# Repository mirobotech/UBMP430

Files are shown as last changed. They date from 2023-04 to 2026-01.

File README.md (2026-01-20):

# UBMP430
 
UBMP430 (USB-Based Beginner Multipurpose Project 4, rev. 3) KiCad schematic and PCB design files.

UBMP430 is a simple, versatile, and inexpensive microcontroller development system for everyone! The UBMP430 circuit board has a variety of simple I/O devices built-in so beginners can learn to code and make an assortment of different projects using just the parts on UBMP430 – no breadboarding, shields, or other modules are required, and external devices can be added using the expansion header. 

UBMP430 was designed for learning or teaching PIC programming in C or assembly language using either Microchip’s MPLAB X IDE or their MPLAB Xpress Cloud-based IDE. The [USB µC bootloader](https://hackaday.io/project/63204-usb-c-usb-pic-bootloader) allows UBMP430 to appear as a mass storage drive for easy programming. Simply drag and drop a compiled .hex file onto the ***PIC16F1459*** drive that shows up in your computer's device manager, and your program will start to run as soon as the file is transferred.

The bootloader makes it possible to program UBMP430 using almost any kind of device, even enabling schools with 1:1 Chromebook programs to teach real C language microcontroller programming with Github integration.

## UBMP430 Hardware Features

- Microchip PIC16F1459 USB-capable microcontroller with 8k words of program FLASH (6k words free when using the USB µC bootloader), 128B of user FLASH, 1kB of RAM, 10-bit ADC, and a built-in temperature sensor
- 5 built-in pushbuttons
- 5 visible light LEDs
- 1 piezo beeper output
- optional 8-pin header for PORTC I/O pin expansion (great for servos, a SONAR module, NeoPixels, an LCD display, etc.)
- optional IR LED output for remote control transmitter applications (or a high-current transistor-driven output)
- optional IR demodulator for remote control decoding
- optional IR phototransistor or visible-light ambient light sensor for light sensing
- USB 2.0 type-C port for power and programming (updated 
- 6-pin ICSP (In-Circuit Serial Programming) header for PICkit-4

## UMBP430 is Open

UBMP430 is open hardware and uses open source software – we want educators to have full access to the circuit, lesson materials, and code. The following permissions and conditions apply to UBMP430:
- the KiCad UBMP430 files stored in GitHub are open hardware licensed under the terms of the MIT license (except the mirobo.tech logo - see below). You are free to use and modify the UBMP430 files to make your own UBMP430 circuit boards.
- UBMP430 programs stored in GitHub are open source software licensed under the terms of the MIT license.
- UMBP430 learning materials on the mirobo.tech website are licensed under the terms of the Creative Commons CC-BY 4.0 license.
- the USB uC bootloader is open source and licensed under the terms of the GPL3.0 license by John Izzard.
- the mirobo.tech logo mark is a trademark of mirobo Technolgy and may not be used without prior permission.

## Can I buy a UBMP430?

UBMP430 boards, kits, and lab packs are available at [mirobo.tech](https://mirobo.tech/ubmp4).  
Bare UBMP430 printed circuit boards are also available from [OSHPARK](https://oshpark.com/shared_projects/tnwOOjI0).

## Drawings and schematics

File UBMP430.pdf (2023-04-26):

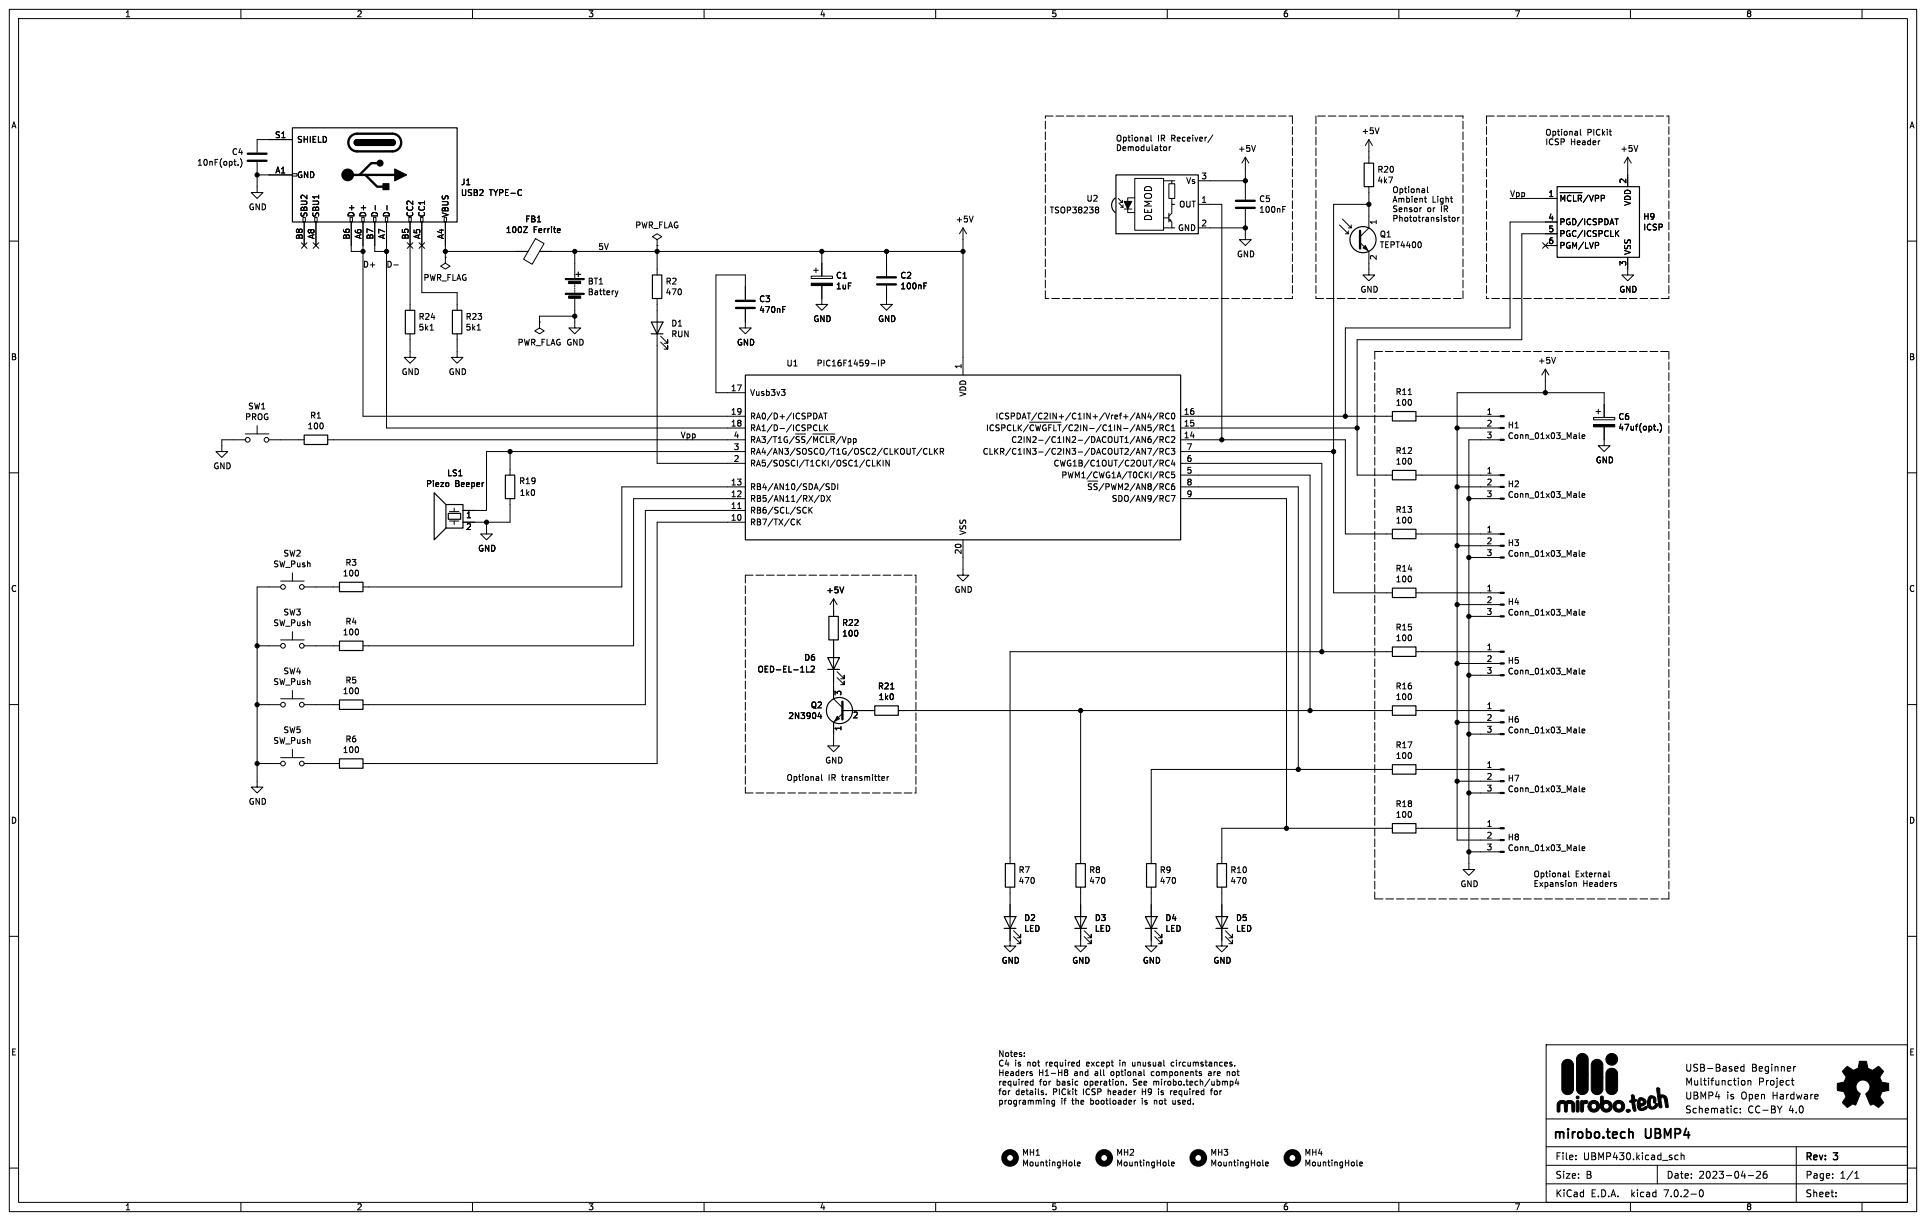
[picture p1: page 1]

ICSP Header Optional IR transmitter

Optional IR Receiver/ Demodulator

Optional Ambient Light Sensor or IR

3 PGD/ICSPDAT 4 PGC/ICSPCLK 5 PGM/LVP 6 H9

3 PGD/ICSPDAT 4 PGC/ICSPCLK 5 PGM/LVP 6

1 RB7/TX/CK 10 RB6/SCL/SCK 11 RB5/AN11/RX/DX 12 RB4/AN10/SDA/SDI 13 C2IN2-/C1IN2-/DACOUT1/AN6/RC2 14 ICSPCLK/~{CWGFLT}/C2IN-/C1IN-/AN5/RC1

Optional External Expansion Headers

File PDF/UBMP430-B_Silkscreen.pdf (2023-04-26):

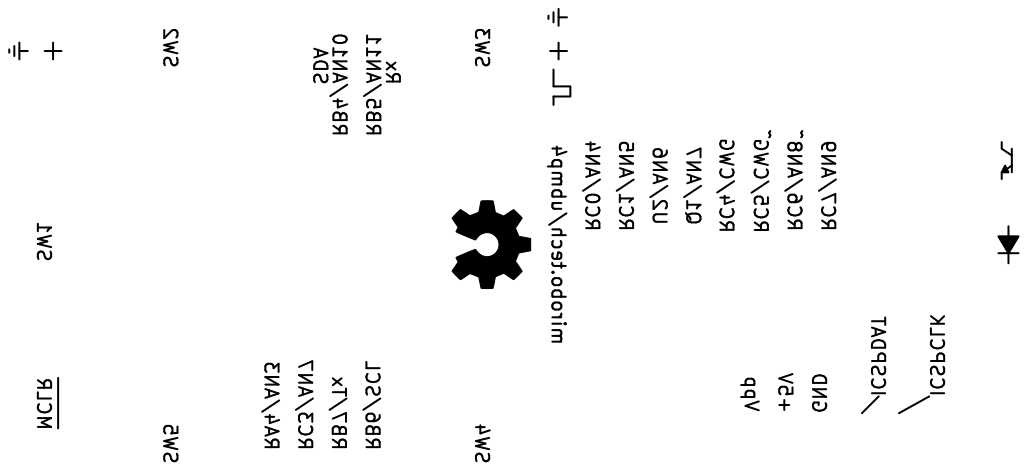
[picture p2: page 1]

RA4/AN3 Vpp SW4 SDA RB5/AN11 GND RC6/AN8 SW2 mirobo.tech/ubmp4 ICSPDAT +5V RC5/CWG Q1/AN7 ~U2/AN6 SW1 ICSPCLK RB4/AN10 RB7/Tx MCLR RC7/AN9 RC3/AN7 RB6/SCL RC4/CWG Rx RC0/AN4 RC1/AN5 SW3 ~ SW5

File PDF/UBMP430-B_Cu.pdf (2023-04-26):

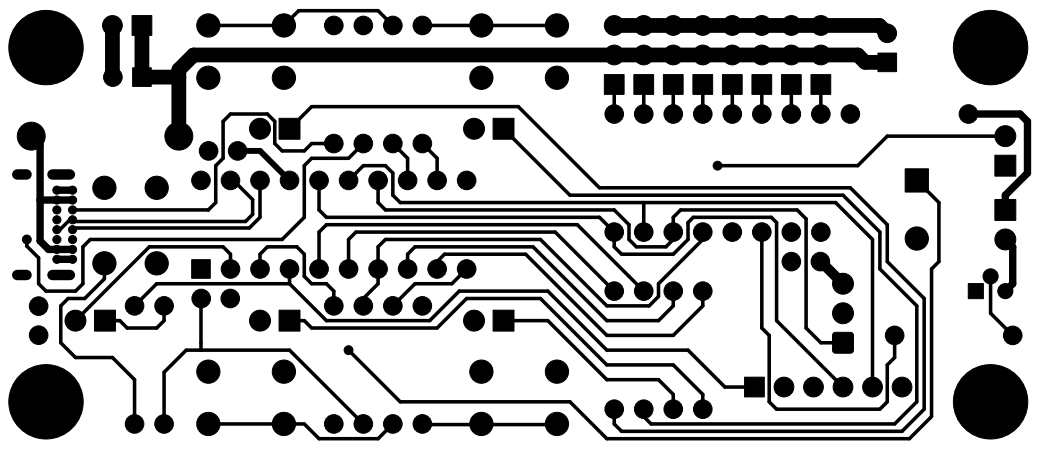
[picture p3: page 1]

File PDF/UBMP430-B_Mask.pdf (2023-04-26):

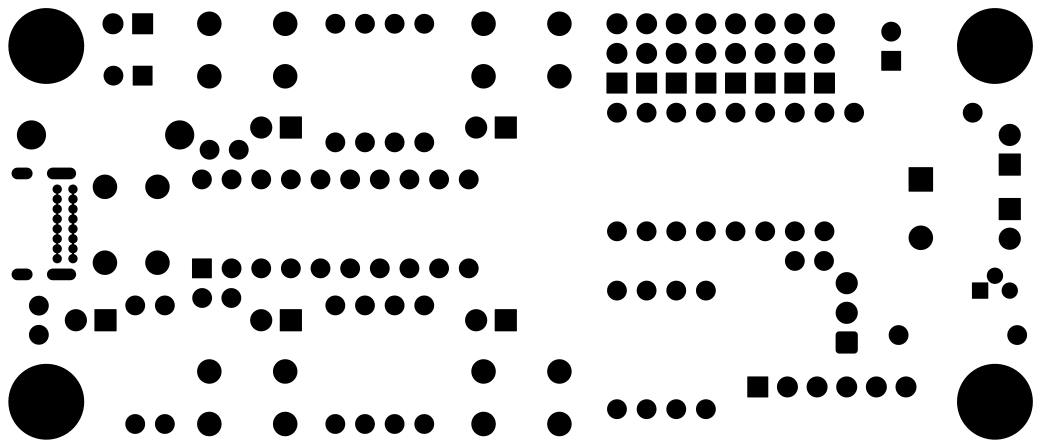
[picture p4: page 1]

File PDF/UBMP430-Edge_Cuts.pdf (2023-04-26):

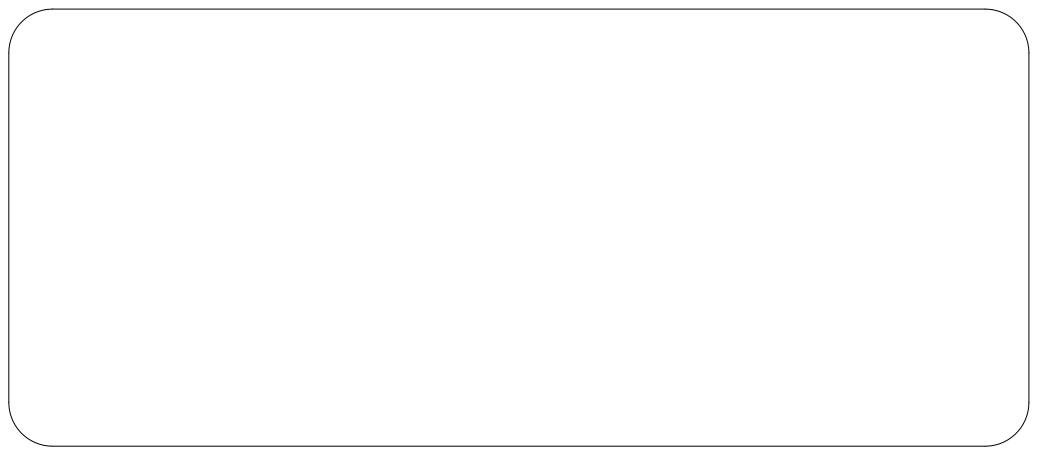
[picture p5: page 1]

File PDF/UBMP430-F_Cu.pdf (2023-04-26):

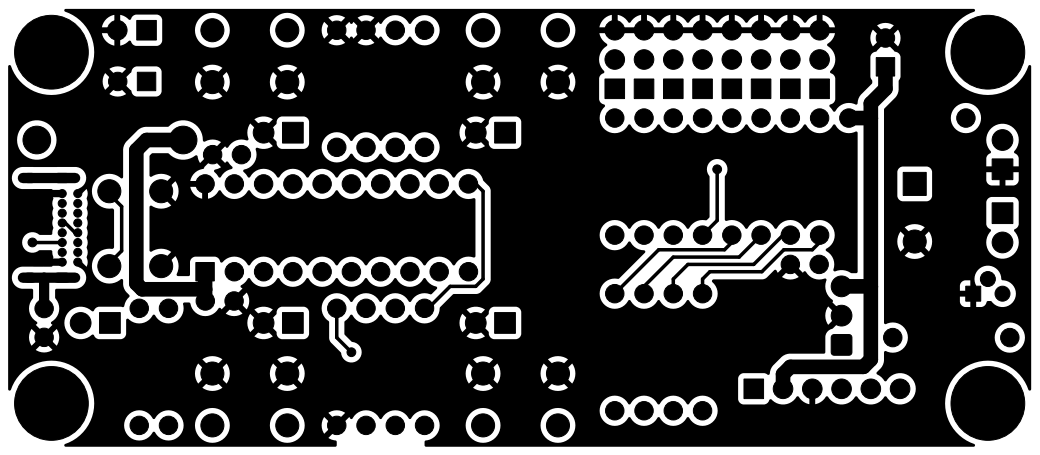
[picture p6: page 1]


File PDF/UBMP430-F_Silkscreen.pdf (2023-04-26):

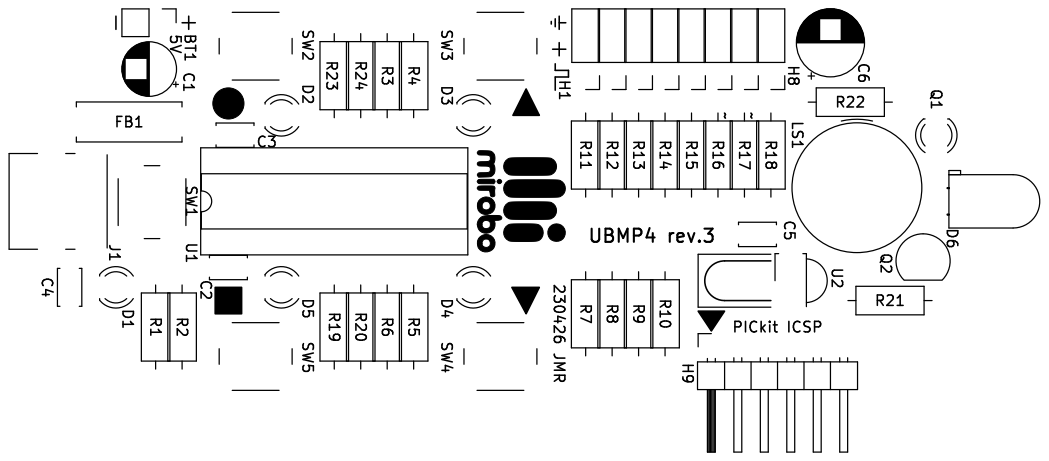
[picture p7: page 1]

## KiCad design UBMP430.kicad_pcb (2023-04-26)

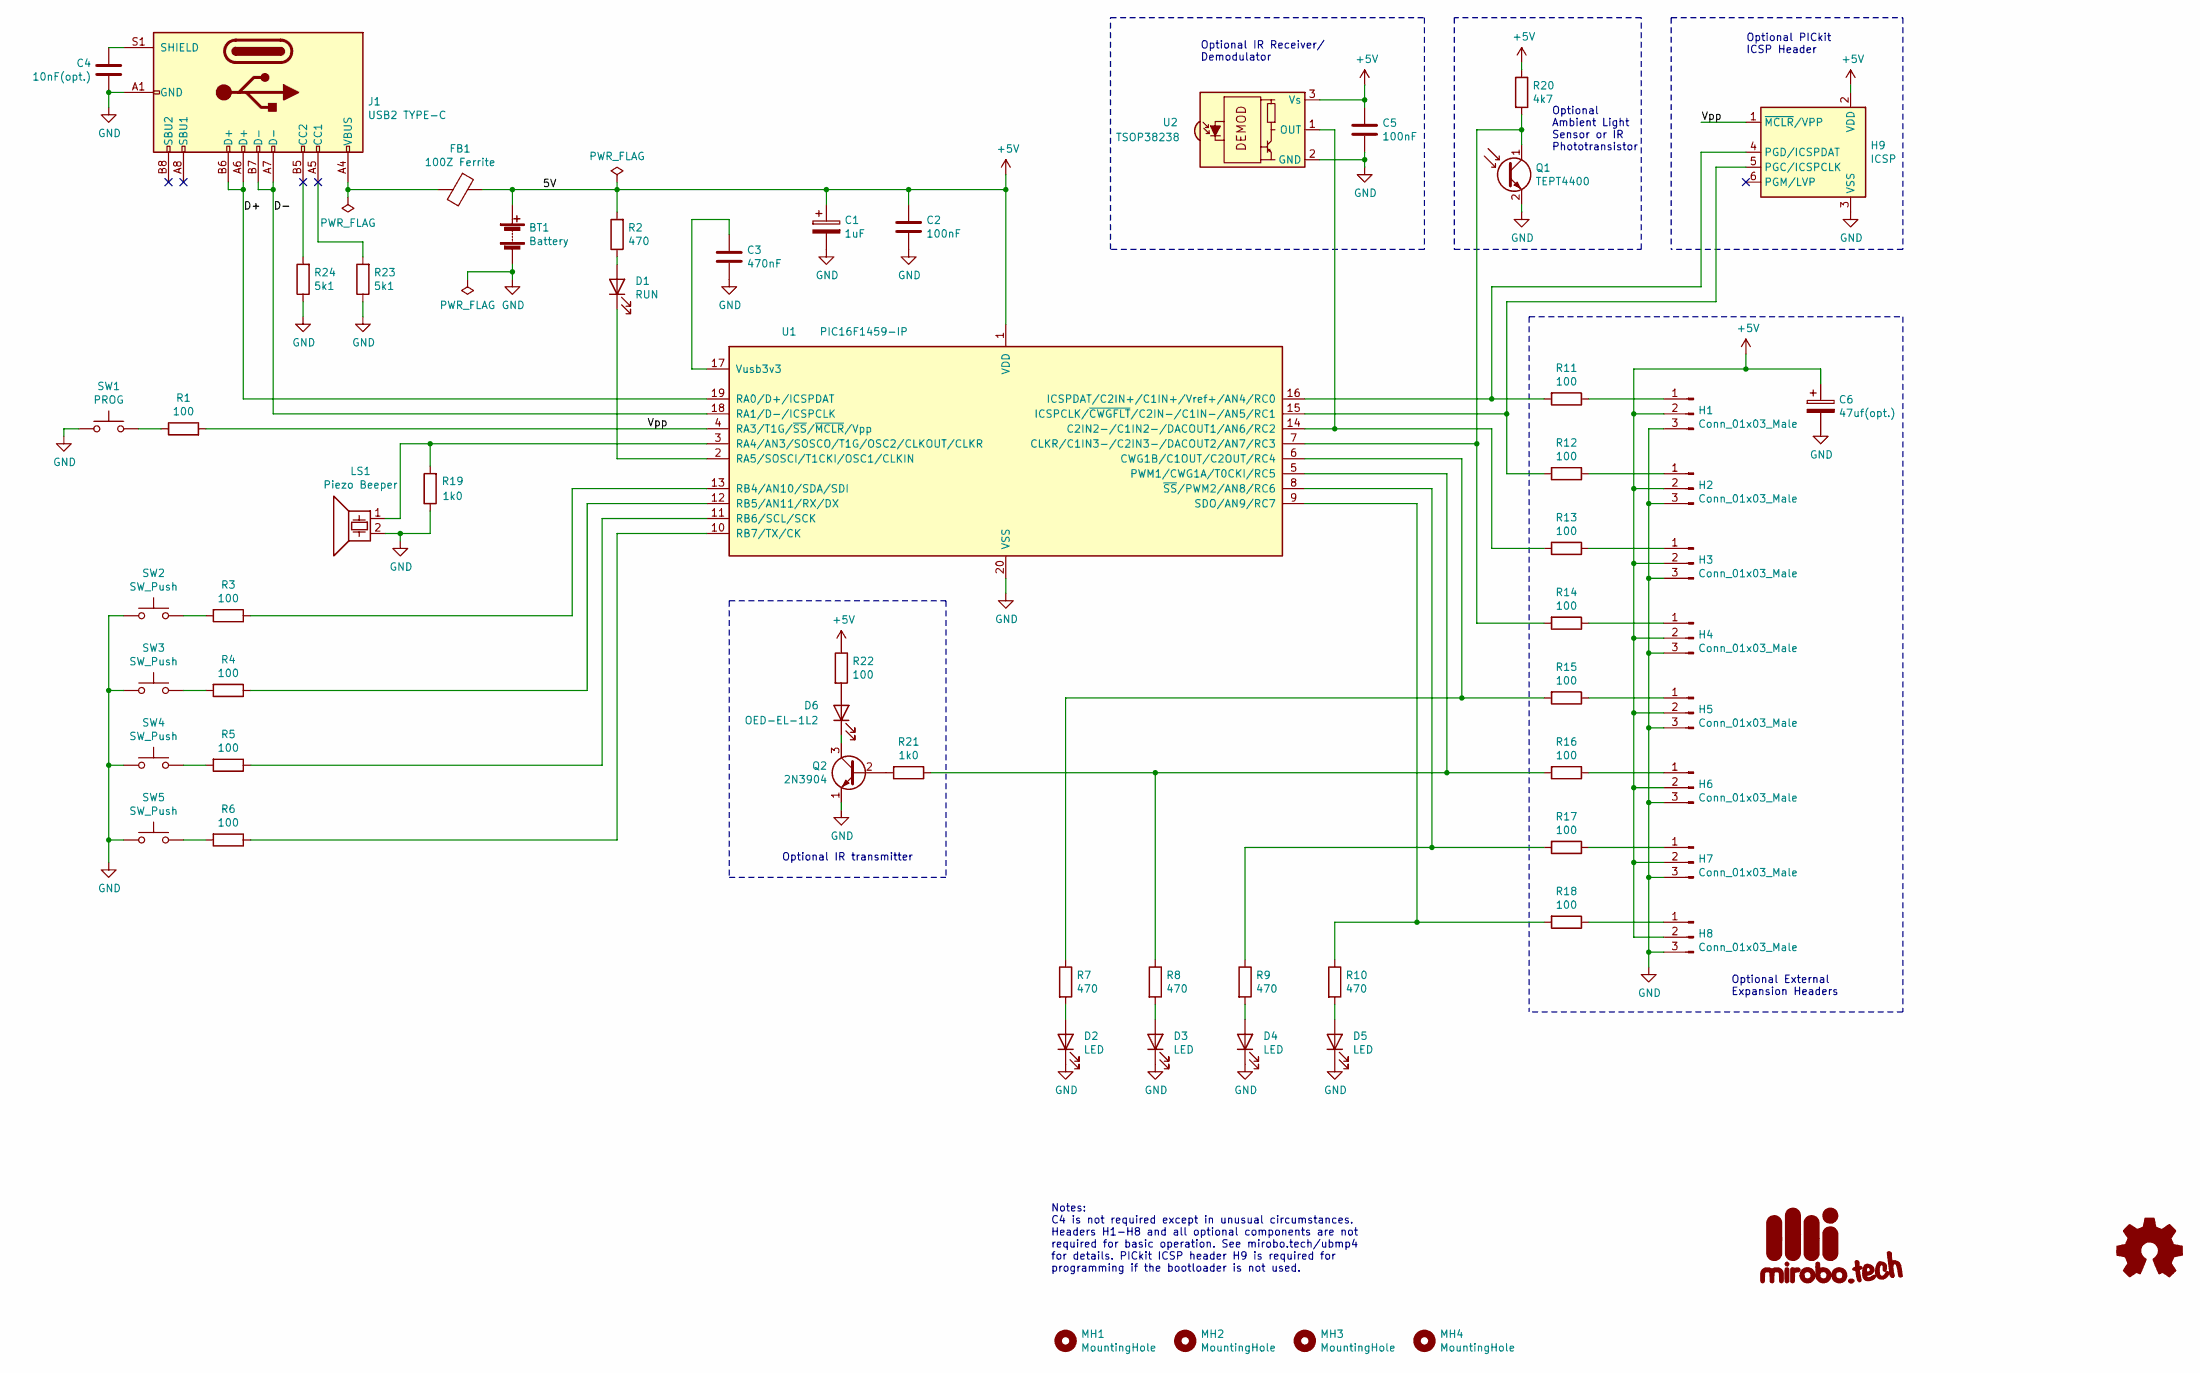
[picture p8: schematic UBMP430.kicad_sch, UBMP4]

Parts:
BT1: Battery; PinHeader_1x02_P2.54mm_Vertical
C1: 1uF; CP_Radial_D5.0mm_P2.50mm
C2, C5: 100nF; C_Disc_D3.4mm_W2.1mm_P2.50mm
C3: 470nF; C_Disc_D3.4mm_W2.1mm_P2.50mm
C4: 10nF(opt.); C_Disc_D3.4mm_W2.1mm_P2.50mm
C6: 47uf(opt.); CP_Radial_D6.3mm_P2.50mm
D1: RUN; LED_D3.0mm
D2, D3, D4, D5: LED; LED_D3.0mm
D6: OED-EL-1L2; LED_D5.0mm_Horizontal_O1.27mm_Z3.0mm_Clear
FB1: 100Z Ferrite; R_Axial_DIN0411_L9.9mm_D3.6mm_P12.70mm_Horizontal
G1: mirobotech_logo; mirobo_logo_10
G2: Logo_Open_Hardware_Small; OSHW-Symbol_6.7x6mm_SilkScreen
H1, H2, H3, H4, H5, H6, H7, H8: Conn_01x03_Male; PinHeader_1x03_P2.54mm_Vertical
H9: ICSP; PinHeader_1x06_P2.54mm_Horizontal
J1: USB2 TYPE-C; USB_C_Receptacle_GCT_USB4085
LS1: Piezo Beeper; Buzzer_TDK_PS1240P02BT_D12.2mm_H6.5mm
MH1, MH2, MH3, MH4: MountingHole; MountingHole_3.2mm_M3_Pad
Q1: TEPT4400; LED_D3.0mm_Clear
Q2: 2N3904; TO-92
R1, R3, R4, R5, R6, R11, R12, R13, R14, R15, R16, R17, R18, R22: 100; R_Axial_DIN0207_L6.3mm_D2.5mm_P10.16mm_Horizontal
R2, R7, R8, R9, R10: 470; R_Axial_DIN0207_L6.3mm_D2.5mm_P10.16mm_Horizontal
R19, R21: 1k0; R_Axial_DIN0207_L6.3mm_D2.5mm_P10.16mm_Horizontal
R20: 4k7; R_Axial_DIN0207_L6.3mm_D2.5mm_P10.16mm_Horizontal
R23, R24: 5k1; R_Axial_DIN0207_L6.3mm_D2.5mm_P10.16mm_Horizontal
SW1: PROG; SW_PUSH_6mm
SW2, SW3, SW4, SW5: SW_Push; SW_PUSH_6mm
U1: PIC16F1459-IP; DIP-20_W7.62mm_Socket
U2: TSOP38238; Vishay_MINICAST-3Pin

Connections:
+5V: BT1.1 (+), C1.1, C2.1, C5.1, C6.1, FB1.1, H1.2, H2.2, H3.2, H4.2, H5.2, H6.2, H7.2, H8.2, H9.2 (VDD), R2.2, R20.1, R22.1, U1.1 (VDD), U2.3 (Vs)
/D+: J1.A6 (D+), J1.B6 (D+), U1.19 (RA0/D+/ICSPDAT)
/D-: J1.A7 (D-), J1.B7 (D-), U1.18 (RA1/D-/ICSPCLK)
/Vpp: H9.1 (~MCLR/VPP), R1.2, U1.4 (RA3/T1G/~SS/~MCLR/Vpp)
GND: BT1.2 (-), C1.2, C2.2, C3.2, C4.1, C5.2, C6.2, D2.1 (K), D3.1 (K), D4.1 (K), D5.1 (K), H1.3, H2.3, H3.3, H4.3, H5.3, H6.3, H7.3, H8.3, H9.3 (VSS), J1.A1 (GND), J1.A12 (GND), J1.B1 (GND), J1.B12 (GND), LS1.2, Q1.2 (E), Q2.1 (E), R19.1, R23.1, R24.1, SW1.1, SW2.1, SW3.1, SW4.1, SW5.1, U1.20 (VSS), U2.2 (GND)
unnamed: FB1.2, J1.A4 (VBUS), J1.A9 (VBUS), J1.B4 (VBUS), J1.B9 (VBUS)
unnamed: D1.2 (A), R2.1
unnamed: D1.1 (K), U1.2 (RA5/SOSCI/T1CKI/OSC1/CLKIN)
unnamed: D2.2 (A), R7.2
unnamed: D3.2 (A), R8.2
unnamed: D4.2 (A), R9.2
unnamed: D5.2 (A), R10.2
unnamed: D6.2 (A), R22.2
unnamed: D6.1 (K), Q2.3 (C)
unnamed: H1.1, R11.1
unnamed: H2.1, R12.1
unnamed: H3.1, R13.1
unnamed: H4.1, R14.1
unnamed: H5.1, R15.1
unnamed: H6.1, R16.1
unnamed: H7.1, R17.1
unnamed: H8.1, R18.1
unnamed: H9.5 (PGC/ICSPCLK), R12.2, U1.15 (ICSPCLK/~CWGFLT/C2IN-/C1IN-/AN5/RC1)
unnamed: H9.4 (PGD/ICSPDAT), R11.2, U1.16 (ICSPDAT/C2IN+/C1IN+/Vref+/AN4/RC0)
unnamed: C4.2, J1.S1 (SHIELD)
unnamed: Q1.1 (C), R14.2, R20.2, U1.7 (CLKR/C1IN3-/C2IN3-/DACOUT2/AN7/RC3)
unnamed: Q2.2 (B), R21.2
unnamed: R1.1, SW1.2
unnamed: R3.2, SW2.2
unnamed: R4.2, SW3.2
unnamed: R5.2, SW4.2
unnamed: R6.2, SW5.2
unnamed: R13.2, U1.14 (C2IN2-/C1IN2-/DACOUT1/AN6/RC2), U2.1 (OUT)
unnamed: R7.1, R15.2, U1.6 (CWG1B/C1OUT/C2OUT/RC4)
unnamed: R8.1, R16.2, R21.1, U1.5 (PWM1/CWG1A/T0CKI/RC5)
unnamed: LS1.1, R19.2, U1.3 (RA4/AN3/SOSCO/T1G/OSC2/CLKOUT/CLKR)
unnamed: R3.1, U1.13 (RB4/AN10/SDA/SDI)
unnamed: R4.1, U1.12 (RB5/AN11/RX/DX)
unnamed: R5.1, U1.11 (RB6/SCL/SCK)
unnamed: R6.1, U1.10 (RB7/TX/CK)
unnamed: R10.1, R18.2, U1.9 (SDO/AN9/RC7)
unnamed: C3.1, U1.17 (Vusb3v3)
unnamed: R9.1, R17.2, U1.8 (~SS/PWM2/AN8/RC6)

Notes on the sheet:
Notes: C4 is not required except in unusual circumstances. Headers H1-H8 and all optional components are not required for basic operation. See mirobo.tech/ubmp4 for details. PICkit ICSP header H9 is required for programming if the bootloader is not used.
Optional IR transmitter
Optional External Expansion Headers
Optional Ambient Light Sensor or IR Phototransistor
Optional IR Receiver/ Demodulator
Optional PICkit ICSP Header

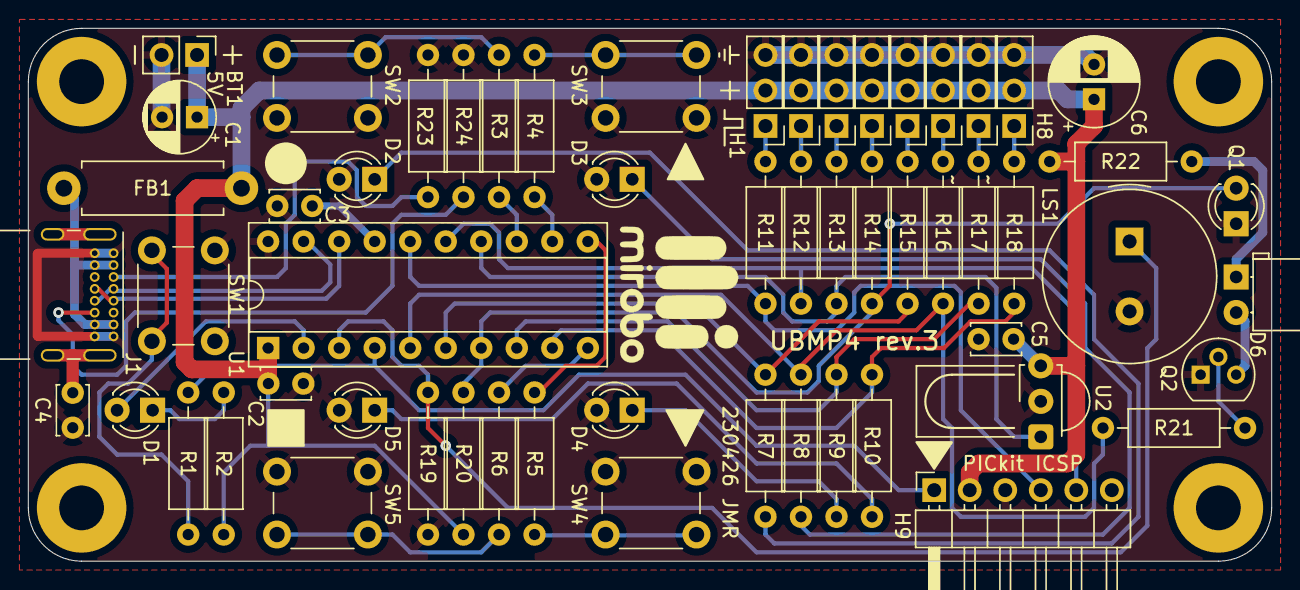
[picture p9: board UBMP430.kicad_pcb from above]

Board: 2 copper layers, 88.9 x 38.1 mm, 64 parts (1 on the bottom side), 43 nets.

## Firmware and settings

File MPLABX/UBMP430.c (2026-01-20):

/* =============================================================================
 * File: UBMP430.c
 * Date: January 20, 2026
 * 
 * UBMP4.3 (PIC16F1459) hardware functions
 * ===========================================================================*/

#include "xc.h"                 // XC compiler general include file

#include "stdint.h"             // Include integer definitions
#include "stdbool.h"            // Include Boolean (true/false) definitions

#include "UBMP430.h"

/* =========================================================
 * Millisecond timer (Timer0) interrupt function
 * ========================================================= */

volatile uint32_t millis_count = 0;

/*
 * Timer0 setup: Fosc = 48 MHz
 * Instruction clock = Fosc / 4 = 12 MHz
 * Timer0 pre-scaler = 1:64
 *
 * Timer tick = 64 / 12 MHz = 5.333 us
 * 1 ms / 5.333us = 187.5 ticks
 * 256 - 188 = 68 = pre-load value (won't be precisely 1ms, but close)
 */

void __interrupt() ISR(void) {
    if (TMR0IF) {               // If Timer 0 overflowed:
        TMR0IF = 0;             // Clear Timer 0 interrupt flag
        TMR0 = 68;              // Pre-load Timer 0 for next ms period
        millis_count++;         // Increment milliseconds count
    }
}

/* =========================================================
 * UBMP4 initialization function
 * ========================================================= */

void UBMP4_Init(void) {

    /* Oscillator configuration */
    OSCCON = 0xFC;              // Set 16MHz HFINTOSC with 3x PLL enabled
    ACTCON = 0x90;              // Enable active clock tuning from USB clock
    while(!PLLRDY);             // Wait for PLL lock (disable for simulation)

    /* OPTION register configuration */
    OPTION_REG = 0b01010101;    // Enable port pull-ups, TMR0 div-64 internal

    /* PORTA configuration */
    LATA = 0b00000000;          // Clear Port A latches before configuring PORTA
    TRISA = 0b00001111;         // Set LED_D1 (RUN) and Beeper pins as outputs
    ANSELA = 0b00000000;        // Disable analog input on all PORT A input pins
    WPUA = 0b00001000;          // Enable weak pull-up on SW1 (RESET) input only

    /* PORTB configuration */
    LATB = 0b00000000;          // Clear Port B latches before configuring PORTB
    TRISB = 0b11110000;         // Enable pushbutton pins as inputs (SW2-SW5)
    ANSELB = 0b00000000;        // Disable analog input on all PORT B input pins
    WPUB = 0b11110000;          // Enable weak pull-ups on all pushbutton inputs

    /* PORTC configuration */
    LATC = 0b00000000;          // Clear Port C latches before configuring PORTC
    TRISC = 0b00001111;         // Set LED pins as outputs, H1-H4 pins as inputs
    ANSELC = 0b00000000;        // Disable analog input on all PORT C input pins

    /* Timer0 configuration and startup (used for milliseconds counter) */
    TMR0 = 68;                  // Pre-load Timer0 with millis() offset
    TMR0IF = 0;                 // Ensure Timer0 Interrupt Flag is cleared
    TMR0IE = 1;                 // Enable Timer0 interrupt
    GIE = 1;                    // Enable global interrupts
    
}

/* =========================================================
 * Timing functions
 * ========================================================= */

void delay_us(uint16_t us) {
    if (us <= 1) return;
    us--;
    while (us--) _delay(1);
}

void delay_ms(uint16_t ms) {
    while (ms--) delay_us(992);
}

uint32_t millis(void) {
    return millis_count;
}

/* =========================================================
 * ADC functions
 * ========================================================= */

void ADC_Init(void) {
    // Configure ADC input for on-board phototransistor Q1 (AN7).
    // TODO: Disable digital output driver for any other required ADC input pins
    TRISCbits.TRISC3 = 1;       // Disable output driver (TRISx.bit = 1)
    // TODO: Enable analog input for any other required ADC input pins
    ANSELC = 0b00001000;        // Enable Q1 analog input (ANSELx.bit = 1)
    
    // General ADC setup and configuration
    ADCON0 = 0b00011100;        // Set channel to AN7, leave A/D converter off
    ADCON1 = 0b11100000;        // Right justified result, FOSC/64 clock, +VDD ref
    ADCON2 = 0b00000000;        // Auto-conversion trigger disabled
}

void ADC_Set_Channel(uint8_t channel) {
    ADON = 1;                   // Turn the A-D converter on
    ADCON0 &= 0b10000011;       // AND to clear channel select (CHS) bits
    ADCON0 |= channel;          // OR channel constant to select input channel
}

uint16_t ADC_Read(void) {
    ADCON1bits.ADFM = 1;        // Set right justified result
    GO = 1;                     // Start the conversion by setting Go/^Done bit
	while(GO)                   // Wait for the conversion to finish (GO==0)
        ;                       // (Suppresses warning from empty while loop)
    return ((uint16_t)ADRESH << 8) | ADRESL;    // Return 16-bit result
}

uint8_t ADC_Read_8bits(void) {
    ADCON1bits.ADFM = 0;        // Set left justified result
    GO = 1;                     // Start the conversion by setting Go/^Done bit
	while(GO)                   // Wait for the conversion to finish (GO==0)
        ;                       // (Suppresses warning from empty while loop)
    return (ADRESH);            // Return top 8-bits of result    
}

uint16_t ADC_Read_Channel(uint8_t channel) {
    ADCON1bits.ADFM = 1;        // Set right justified result
    ADON = 1;                   // Turn the A-D converter on
    ADCON0 &= 0b10000011;       // AND to clear channel select (CHS) bits
    ADCON0 |= channel;          // OR channel constant to select input channel
    __delay_us(5);              // Allow input to settle after channel change
    GO = 1;                     // Start the conversion by setting Go/^Done bit
	while(GO)                   // Wait for the conversion to finish (GO==0)
        ;                       // (Suppresses warning from empty while loop)
    ADON = 0;                   // Turn the A-D converter off
    return ((uint16_t)ADRESH << 8) | ADRESL;    // Return 16-bit result
}

/* =========================================================
 * PWM functions (designed to create 38kHz output on LED6)
 * ========================================================= */

void PWM1_Start(uint16_t freq) {
    uint16_t pr;

    if (freq == 0) return;

    T2CON = 0b00000101;         // Turn Timer2 on, pre-scaler 1:4, post-scaler 1:1
    
    /*
     * PR2 = (Fosc / (4 * pre-scaler * freq)) - 1
     * Pre-scaler = 64
     */
    pr = (_XTAL_FREQ / (4UL * 4UL * freq)) - 1;
    if (pr > 255) pr = 255;
    
    PR2 = pr;
    PWM1DCH = (pr + 1) >> 1;   // ~50% duty
    PWM1DCL = 0;
    PWM1CON = 0b11000000;      // Enable PWM1 output
}

void PWM1_On(void) {
    PWM1CON = 0b11000000;       // Enable PWM1 output
}

void PWM1_Off(void) {
    PWM1CON = 0b10000000;       // Disable PWM1 output
}
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

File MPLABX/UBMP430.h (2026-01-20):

/* =============================================================================
 * File: UBMP430.h
 * Date: January 20, 2026
 * 
 * UBMP4.3 hardware definitions and function prototypes (PIC16F1459 in USB mode)
 * ===========================================================================*/

#ifndef UBMP430_H
#define UBMP430_H

#define _XTAL_FREQ  48000000UL      // Set clock frequency for timing functions

/* =====================================
 * UBMP4 hardware definitions
 * ===================================== */

// PORTA
#define MCLR        PORTAbits.RA3   // SW1/PROG/Reset (MCLR) pushbutton input
#define SW1         PORTAbits.RA3   // SW1/PROG/Reset (MCLR) pushbutton input
#define BEEPER      LATAbits.LATA4  // Piezo beeper (LS1) output
#define	LS1         LATAbits.LATA4  // Piezo beeper (LS1) output
#define LED1        LATAbits.LATA5  // LED D1/Run LED output (active-low)

// PORTB I/O
#define SW2         PORTBbits.RB4   // Pushbutton SW2 input
#define SW3         PORTBbits.RB5   // Pushbutton SW3 input
#define SW4         PORTBbits.RB6   // Pushbutton SW4 input
#define SW5         PORTBbits.RB7   // Pushbutton SW5 input

// PORTC
#define H1IN        PORTCbits.RC0   // External I/O header H1 input
#define H1OUT       LATCbits.LATC0  // External I/O header H1 output

#define H2IN        PORTCbits.RC1   // External I/O header H2 input
#define H2OUT       LATCbits.LATC1  // External I/O header H2 output

#define H3IN        PORTCbits.RC2   // External I/O header H3 input
#define H3OUT       LATCbits.LATC2  // External I/O header H3 output 
#define U2          PORTCbits.RC2   // IR demodulator (U2) input

#define H4IN        PORTCbits.RC3   // External I/O header H4 input
#define H4OUT       LATCbits.LATC3  // External I/O header H4 output
#define Q1          PORTCbits.RC3   // Phototransistor/ambient light sensor (Q1) input

#define H5IN        PORTCbits.RC4   // External I/O header H5 input
#define H5OUT       LATCbits.LATC4  // External I/O header H5 output
#define LED2        LATCbits.LATC4  // LED D2 output

#define H6IN        PORTCbits.RC5   // External I/O header H6 input
#define H6OUT       LATCbits.LATC5  // External I/O header H6 output
#define LED3        LATCbits.LATC5  // LED D3 output
#define LED6        LATCbits.LATC5  // LED D6/IR LED output

#define H7IN        PORTCbits.RC6   // External I/O header H7 input
#define H7OUT       LATCbits.LATC6  // External I/O header H7 output
#define LED4        LATCbits.LATC6  // LED D4 output

#define H8IN        PORTCbits.RC7   // External I/O header H8 input
#define H8OUT       LATCbits.LATC7  // External I/O header H8 output
#define LED5        LATCbits.LATC7  // LED D5 output

/* =====================================
 * ADC channel definitions
 * ===================================== */

#define A3          0b00001100      // A-D converter channel 3 input (LS1)
#define AH1         0b00010000      // External H1 header analogue input (Ch4))
#define A4          0b00010000      // A-D converter channel 4 input
#define AH2         0b00010100      // External H2 header analogue input (Ch5)
#define A5          0b00010100      // A-D converter channel 5 input
#define AH3         0b00011000      // External H3 header analogue input (Ch6)
#define A6          0b00011000      // A-D converter channel 6 input
#define AH4         0b00011100      // External H4 header analogue input (Ch7)
#define A7          0b00011100      // A-D converter channel 7 input
#define AQ1         0b00011100      // Q1 phototransistor A-D input (Ch7)
#define AH7         0b00100000      // External H7 header analogue input (Ch8)
#define A8          0b00100000      // A-D converter channel 8 input
#define AH8         0b00100100      // External H8 header analogue input (Ch9)
#define A9          0b00100100      // A-D converter channel 9 input
#define A10         0b00101000      // A-D converter channel 10 input (SW2 - not used)
#define A11         0b00101100      // A-D converter channel 11 input (SW3 - not used)
#define ATIM        0b01110100      // On-die temperature indicator module input
#define ADAC        0b01111000      // Internal DAC (digital-to-analog converter)
#define AFVR        0b01111100      // Internal fixed voltage reference buffer

/* =====================================
 * Core UBMP4/PIC16F1459 initialization
 * ===================================== */

void UBMP4_Init(void);


/* =====================================
 * Timing functions
 * ===================================== */

void delay_ms(uint16_t ms);
/* Delays for specified number of milliseconds.
 * parameter(s): ms (unsigned int) - number of milliseconds to delay (blocking)
 * returns: nothing
 */

void delay_us(uint16_t us);
/* Delays for specified number of microseconds.
 * parameter(s): us (unsigned int) - number of microseconds to delay (blocking)
 * returns: nothing
 */

uint32_t millis(void);
/* Interrupt-drive milliseconds counter.
 * parameter(s): none
 * returns: milliseconds (unsigned long) since microcontroller start-up
 */


/* =====================================
 * ADC functions
 * ===================================== */

void ADC_Init(void);
/* Configures ADC converter and GPIO to read from on-board phototransistor Q1 (AN7).
 * parameter(s): none
 * returns: nothing
 */

void ADC_Set_Channel(uint8_t channel);
/* Sets ADC input mux to the selected channel.
 * parameter(s): channel constant (unsigned char) encoded with channel select (CHS) bits
 * returns: nothing
 */
uint16_t ADC_Read(void);
/* Reads 10-bit result from currently selected ADC input channel.
 * parameter(s): nothing
 * returns: digital value equivalent to analog input level (10-bits, unsigned int)
 */

uint8_t ADC_Read_8bits(void);
/* Reads 8-bit result from currently selected ADC input channel.
 * parameter(s): nothing
 * returns: digital value equivalent to analog input level (8-bits, unsigned char)
 */

uint16_t ADC_Read_Channel(uint8_t channel);
/* Sets ADC input mux to selected ADC imput channel and reads the 10-bit result.
 * parameter(s): channel constant (unsigned char) encoded with channel select (CHS) bits
 * returns: digital value equivalent to analog input level (10-bits, unsigned int)
 */


/* =====================================
 * PWM functions
 * ===================================== */

void PWM1_Start(uint16_t freq);
/* Starts 50% duty cycle PWM1 output using Timer 2 hardware module (designed for
 * producing 38kHz output for IR transmission).
 * parameter(s): freq (unsigned int) - PWM frequency in Hz (minimum 11765)
 * returns: nothing
 */

void PWM1_On(void);
/* Restarts PWM1 output.
 * parameter(s): none
 * returns: nothing
 */

void PWM1_Off(void);
/* Stops PWM1 output.
 * parameter(s): none
 * returns: nothing
 */

void PWM1_Stop(void);
/* Stops PWM1 output and disables Timer 2.
 * parameter(s): none
 * returns: nothing
 */


/* =====================================
 * Sound function
 * ===================================== */
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

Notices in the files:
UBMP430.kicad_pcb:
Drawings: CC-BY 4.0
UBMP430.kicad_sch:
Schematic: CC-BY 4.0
